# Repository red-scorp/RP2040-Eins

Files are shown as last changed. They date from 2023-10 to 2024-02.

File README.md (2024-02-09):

```
 ______    _______  _______  _______  _   ___  _______         _______  ___   __    _  _______ 
|    _ |  |       ||       ||  _    || | |   ||  _    |       |       ||   | |  |  | ||       |
|   | ||  |    _  ||____   || | |   || |_|   || | |   | ____  |    ___||   | |   |_| ||  _____|
|   |_||_ |   |_| | ____|  || | |   ||       || | |   ||____| |   |___ |   | |       || |_____ 
|    __  ||    ___|| ______|| |_|   ||___    || |_|   |       |    ___||   | |  _    ||_____  |
|   |  | ||   |    | |_____ |       |    |   ||       |       |   |___ |   | | | |   | _____| |
|___|  |_||___|    |_______||_______|    |___||_______|       |_______||___| |_|  |__||_______|
```

# RP2040-Eins Project

The **RP2040-Eins** project aims to create a replacement for the Arduino UNO R3 or Arduino M0 using the RP2040 MCU.

## RP2040-Eins Board

The **RP2040-Eins** board is a 4-layer design intended to accommodate the popular Raspberry Pi RP2040 MCU within the standard Arduino UNO R3 footprint.

This board is crafted in Germany, and its name, "RP2040-Eins", incorporates the German word "Eins" (pronounced as "eye-ns"), which translates to "one". This name choice reflects the use of the same form-factor as the Arduino "Uno", which means "one" in Italian.

Preview:

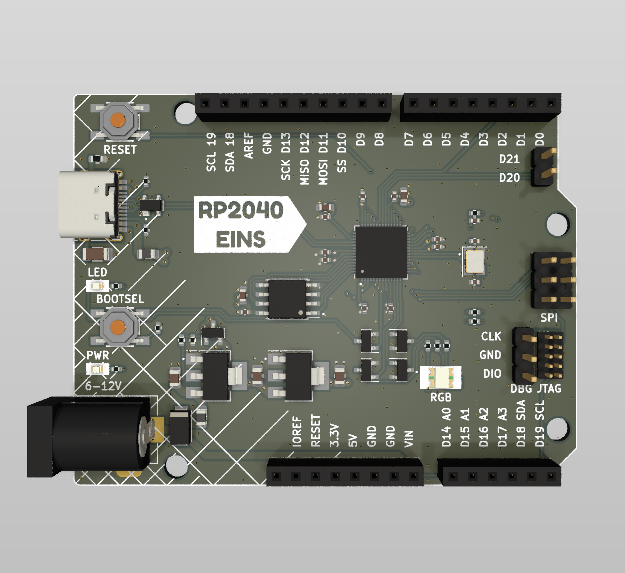
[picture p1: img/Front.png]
RP2040-Eins Front preview

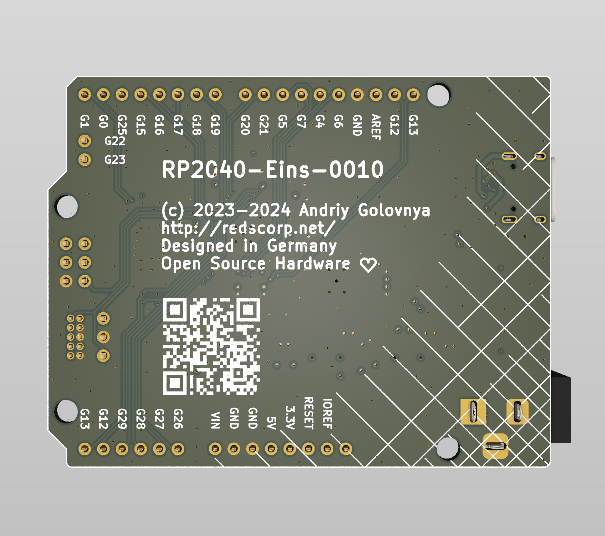
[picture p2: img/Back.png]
RP2040-Eins Back preview

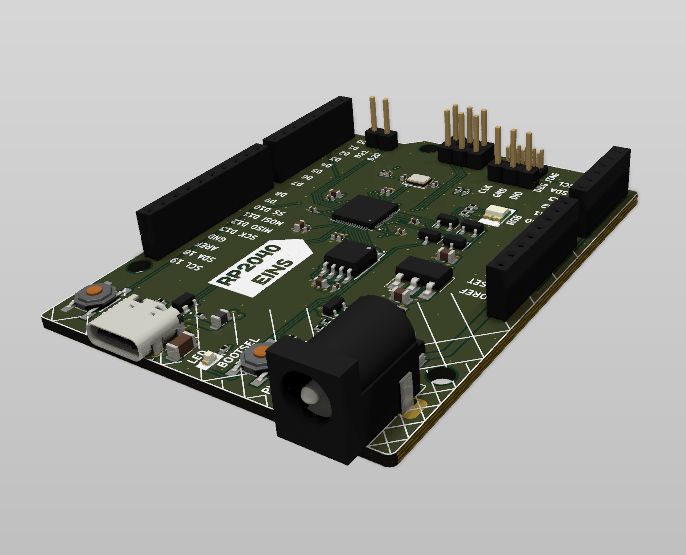
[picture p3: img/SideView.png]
RP2040-Eins Side View preview


You can view the [Schematics in PDF format](doc/RP2040-Eins.pdf) for detailed information.

STEP 3D file is available [with pins](doc/RP2040-Eins.step).

Features:

- Arduino UNO compatible pinout
- Partially compatible with Arduino Nano RP2040 Connect pinout
- Dual-core Cortex-M0+ Raspberry Pi RP2040
- 21 GPIO pins, including 4 analog inputs
- USB Type-C connector
- JTAG and DBG debugging connectors
- LDO-based 5V and 3.3V power supply with a maximum 12V input
- Supports both SOIC and WSON 16MB flash packages
- Includes power, user and RGB LEDs

CAM files, as well as the BOM and CPL files for JLCPCB, are available.

### Board Pinout

Following pinout is used for the board:

| Board Pin | RP2040 Pin | Function | Notes |
| --- | --- | --- | ----- |
| D0 | GPIO1 | UART0 TX | |
| D1 | GPIO0 | UART0 RX | |
| D2 | GPIO25 | | |
| D3 | GPIO15 | | |
| D4 | GPIO16 | | |
| D5 | GPIO17 | | |
| D6 | GPIO18 | | |
| D7 | GPIO19 | | |
| D8 | GPIO20 | | |
| D9 | GPIO21 | | |
| D10 | GPIO5 | SS | |
| D11 | GPIO7 | MOSI | |
| D12 | GPIO4 | MISO | |
| D13 | GPIO6 | SCK | LED |
| D14 A0 | GPIO26 | | |
| D15 A1 | GPIO27 | | |
| D16 A2 | GPIO28 | | |
| D17 A3 | GPIO29 | | |
| D18 | GPIO12 | SDA | |
| D19 | GPIO13 | SCL | |
| D20 | GPIO22 | | |
| D21 | GPIO23 | | |
| LED_R | GPIO9 | | |
| LED_G | GPIO10 | | |
| LED_B | GPIO11 | | |

## Version History

This board exists in a single LDO-based flavor. If you want to use a Buck-based version of this board, please contact me directly.

Each version of the board listed below is tagged in the repository. You can use the tag to checkout the repository to the specific version.

### v1.0b4 - 09.02.2024

v1.0b4 board preview

Last testing release.

- Fixed SPI connector pins layout.
- Renamed Arduino pins as Dxx an added GPIO pin names at the back as Gxx.
- Added 2.54mm 3-pin DBG connector.

### v1.0b3 - 21.11.2023

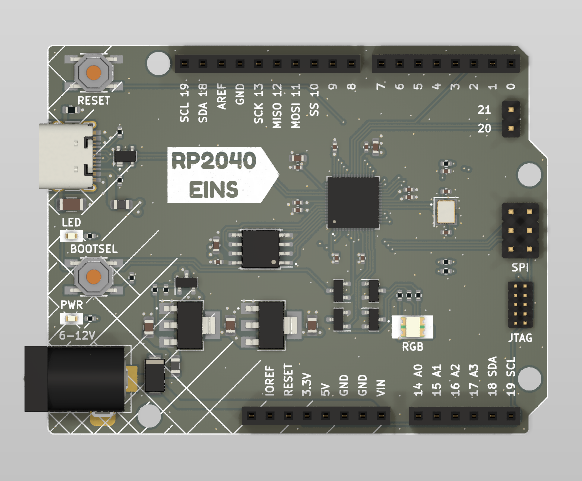
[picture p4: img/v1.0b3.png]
v1.0b3 board preview


Third testing release.

- Moved BOOTSEL button to the edge of the board for easier access when shield is attached.
- Moved QSPI flash closer to the MCU.
- Added Arduino code examples for RGB LED.
- Rearranged routing of several lines.
- Added fancy board name label.
- Added white silkscreen under the LEDs to add light reflection.
- Moved text on the back of the board a bit.
- Removed pull-up resistor from SWCLK line.

### v1.0b2 - 04.11.2023

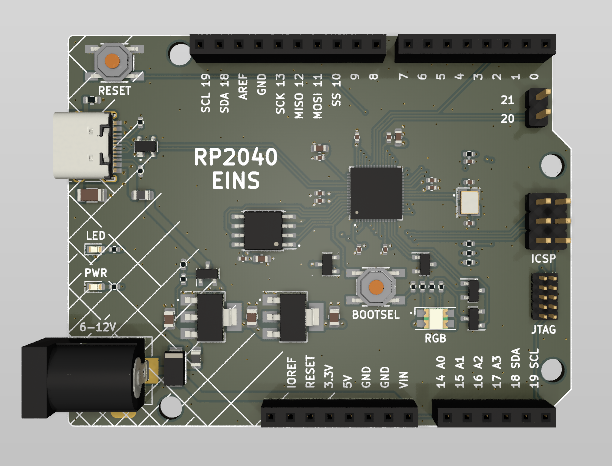
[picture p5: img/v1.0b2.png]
v1.0b2 board preview


Second testing release.

- Added MOSFETs for RGB LED to make it work similarly to user LED.
- Moved few components around.
- Added QR code to the back of the board.

### v1.0b1 - 15.10.2023

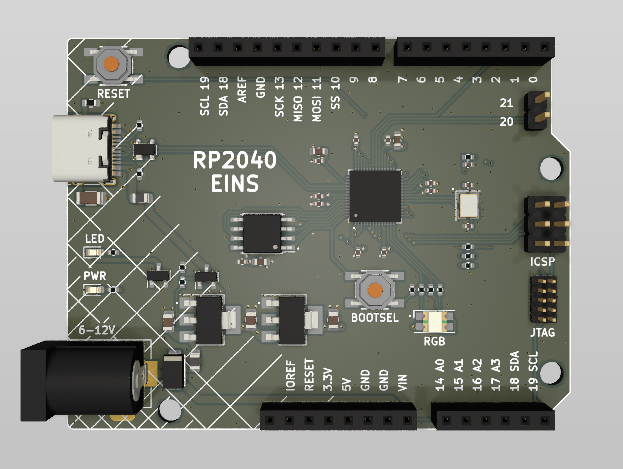
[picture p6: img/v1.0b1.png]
v1.0b1 board preview


Initial release for testing purposes.

## Code Examples

Following code examples are available:

Only Adruino SDK:
- ``src/arduino/rgb_led/rotation_blink.ino`` - blinks RGB LED in rotation individually
- ``src/arduino/rgb_led/rotation_fade.ino`` - fades RGB LED in rotation individually
- ``src/arduino/rgb_led/rotation_fade2.ino`` - fades RGB LED in rotation from one color to another

Arduino SDK with FreeRTOS:
- ``src/arduino/rgb_led/freertos_fade.ino`` - fades RGB LED in rotation individually using FreeRTOS

Please use latest official version of [earlephilhower/arduino-pico](https://github.com/earlephilhower/arduino-pico) and select "RP2040-Eins" board as a target.

## Links

- [Raspberry Pi RP2040 information page](https://www.raspberrypi.com/documentation/microcontrollers/rp2040.html).
- [Arduino UNO R3 information page](https://docs.arduino.cc/retired/boards/arduino-uno-rev3-with-long-pins).
- [Arduino SDK for RP2040 board](https://github.com/earlephilhower/arduino-pico).

## How to Help

Your contributions as code, resources, or finances are welcome! Please contact me directly via email at andriy.golovnya@gmail.com or through my [GitHub profile](https://github.com/red-scorp).

If you'd like to make a financial contribution, you can donate via [PayPal](http://paypal.me/redscorp) or [Ko-Fi](http://ko-fi.com/redscorp). Your support is greatly appreciated.

Thanks in advance!

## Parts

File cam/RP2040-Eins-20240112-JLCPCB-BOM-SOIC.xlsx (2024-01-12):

Qty | Designator | Footprint | JLCPCB Part# | Comment
1 | Q1 | SOT-23 | C15127 | AO3401A
3 | C15,C14,C12 | 0805 | C15850 | 10uF
2 | FB2,FB1 | 0805 | C1015 | GZ2012D101TF
3 | C5,C16,C1 | 0603 | C1604 | 2.2uF
5 | R3,R8,R9,R5,R4 | 0402 | C25744 | 10k
1 | U1 | SOIC-8-208mil | C97521 | W25Q128JVS
1 | SW1,SW2 | SMD | C318884 | TS-1187A-B-A-B
1 | J3 | Plugin,P=2.54mm | C40877 | CONN_A
1 | J1 | Plugin | C16214 | CONN_PWR
7 | R14,R11,R13,R6,R1,R15,R10 | 0402 | C25905 | 5k1
1 | U3 | SOT-223 | C6187 | AMS1117-5.0
1 | D4 | 1210 | C965844 | RGB
1 | Y1 | SMD3225-4P | C9002 | 12MHz
11 | C7,C13,C6,C22,C3,C11,C2,C8,C4,C9,C10 | 0402 | C1525 | 100nF
1 | D5 | SMA(DO-214AC) | C2480 | SS14
1 | U2 | LQFN-56(7x7) | C2040 | RP2040
2 | C20,C19 | 0402 | C1547 | 12pF
2 | D1,D2 | 0603 | C2286 | RED
1 | J4 | Plugin,P=2.54mm | C429957 | CONN_P
4 | Q4,Q3,Q5,Q2 | SOT-23-3L | C20917 | AO3400A
1 | J2 | Plugin,P=2.54mm | C390684 | CONN_ICSP
1 | J9 | Plugin,P=2.54mm | C2935981 | CONN_D2
1 | J7 | SMD,P=1.27mm | C2935953 | JTAG
1 | R7 | 0402 | C11702 | 1k
1 | J10 | SMD | C2689844 | CONN_USB
1 | U5 | SOT-223-3 | C6186 | AMS1117-3.3
1 | C21 | 1206 | C106074 | 4.7nF 1kV
1 | D3 | SOT-143 | C5158049 | PRTR5V0U2X
1 | J8 | Plugin,P=2.54mm | C429957 | CONN_D1
1 | R12 | 0603 | C136593 | 1M
1 | J5 | Plugin,P=2.54mm | C2685154 | CONN_X
1 | J6 | Plugin,P=2.54mm | C2937625 | CONN_DBG

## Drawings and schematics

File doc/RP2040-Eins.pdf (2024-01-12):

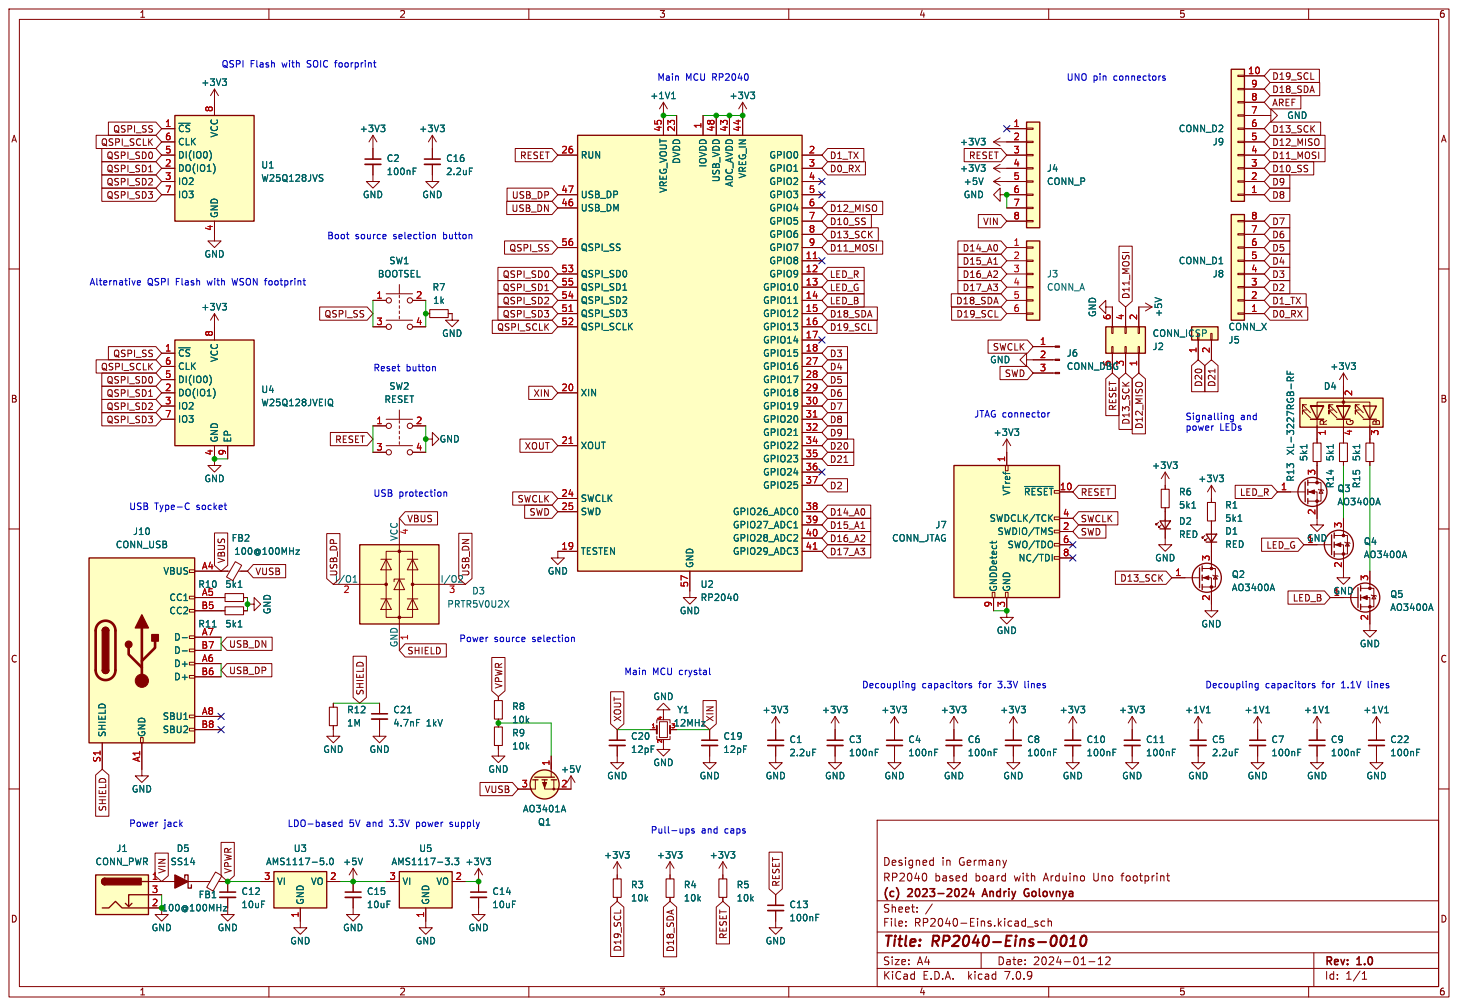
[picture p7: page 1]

1 GPIO8 11 GPIO9 12 GPIO10 13 GPIO11 14 GPIO12 15 GPIO13 16 GPIO14 17 GPIO15 18 TESTEN 19 GPIO0 2 XIN 20 XOUT 21 DVDD 23 SWCLK 24 SWD 25 RUN 26 GPIO16 27 GPIO17 28 GPIO18 29 GPIO1 3 GPIO19 30 GPIO20 31 GPIO21 32 GPIO22 34 GPIO23 35 GPIO24 36 GPIO25 37 GPIO26_ADC0 38 GPIO27_ADC1 39 GPIO2 4 GPIO28_ADC2 40 GPIO29_ADC3 41 ADC_AVDD 43 VREG_IN 44 VREG_VOUT 45 USB_DM 46 USB_DP 47 USB_VDD 48 GPIO3 5 QSPI_SD3 51 QSPI_SCLK 52 QSPI_SD0 53 QSPI_SD2 54 QSPI_SD1 55 QSPI_SS 56 GND 57 GPIO4 6 GPIO5 7 GPIO6 8 GPIO7 9 U2 RP2040 R4

1 GPIO8 11 GPIO9 12 GPIO10 13 GPIO11 14 GPIO12 15 GPIO13 16 GPIO14 17 GPIO15 18 TESTEN 19 GPIO0 2 XIN 20 XOUT 21 DVDD 23 SWCLK 24 SWD 25 RUN 26 GPIO16 27 GPIO17 28 GPIO18 29 GPIO1 3 GPIO19 30 GPIO20 31 GPIO21 32 GPIO22 34 GPIO23 35 GPIO24 36 GPIO25 37 GPIO26_ADC0 38 GPIO27_ADC1 39 GPIO2 4 GPIO28_ADC2 40 GPIO29_ADC3 41 ADC_AVDD 43 VREG_IN 44 VREG_VOUT 45 USB_DM 46 USB_DP 47 USB_VDD 48 GPIO3 5 QSPI_SD3 51 QSPI_SCLK 52 QSPI_SD0 53 QSPI_SD2 54 QSPI_SD1 55 QSPI_SS 56 GND 57 GPIO4 6 GPIO5 7 GPIO6 8 GPIO7 9 R4

XIN QSPI_SD3 XOUT VUSBVPWR SHIELD

3 SWDCLK/TCK 4 SWO/TDO 6 NC/TDI 8 GNDDetect 9 GND
J7 CONN_JTAG

3 SWDCLK/TCK 4 SWO/TDO 6 NC/TDI 8 GNDDetect 9

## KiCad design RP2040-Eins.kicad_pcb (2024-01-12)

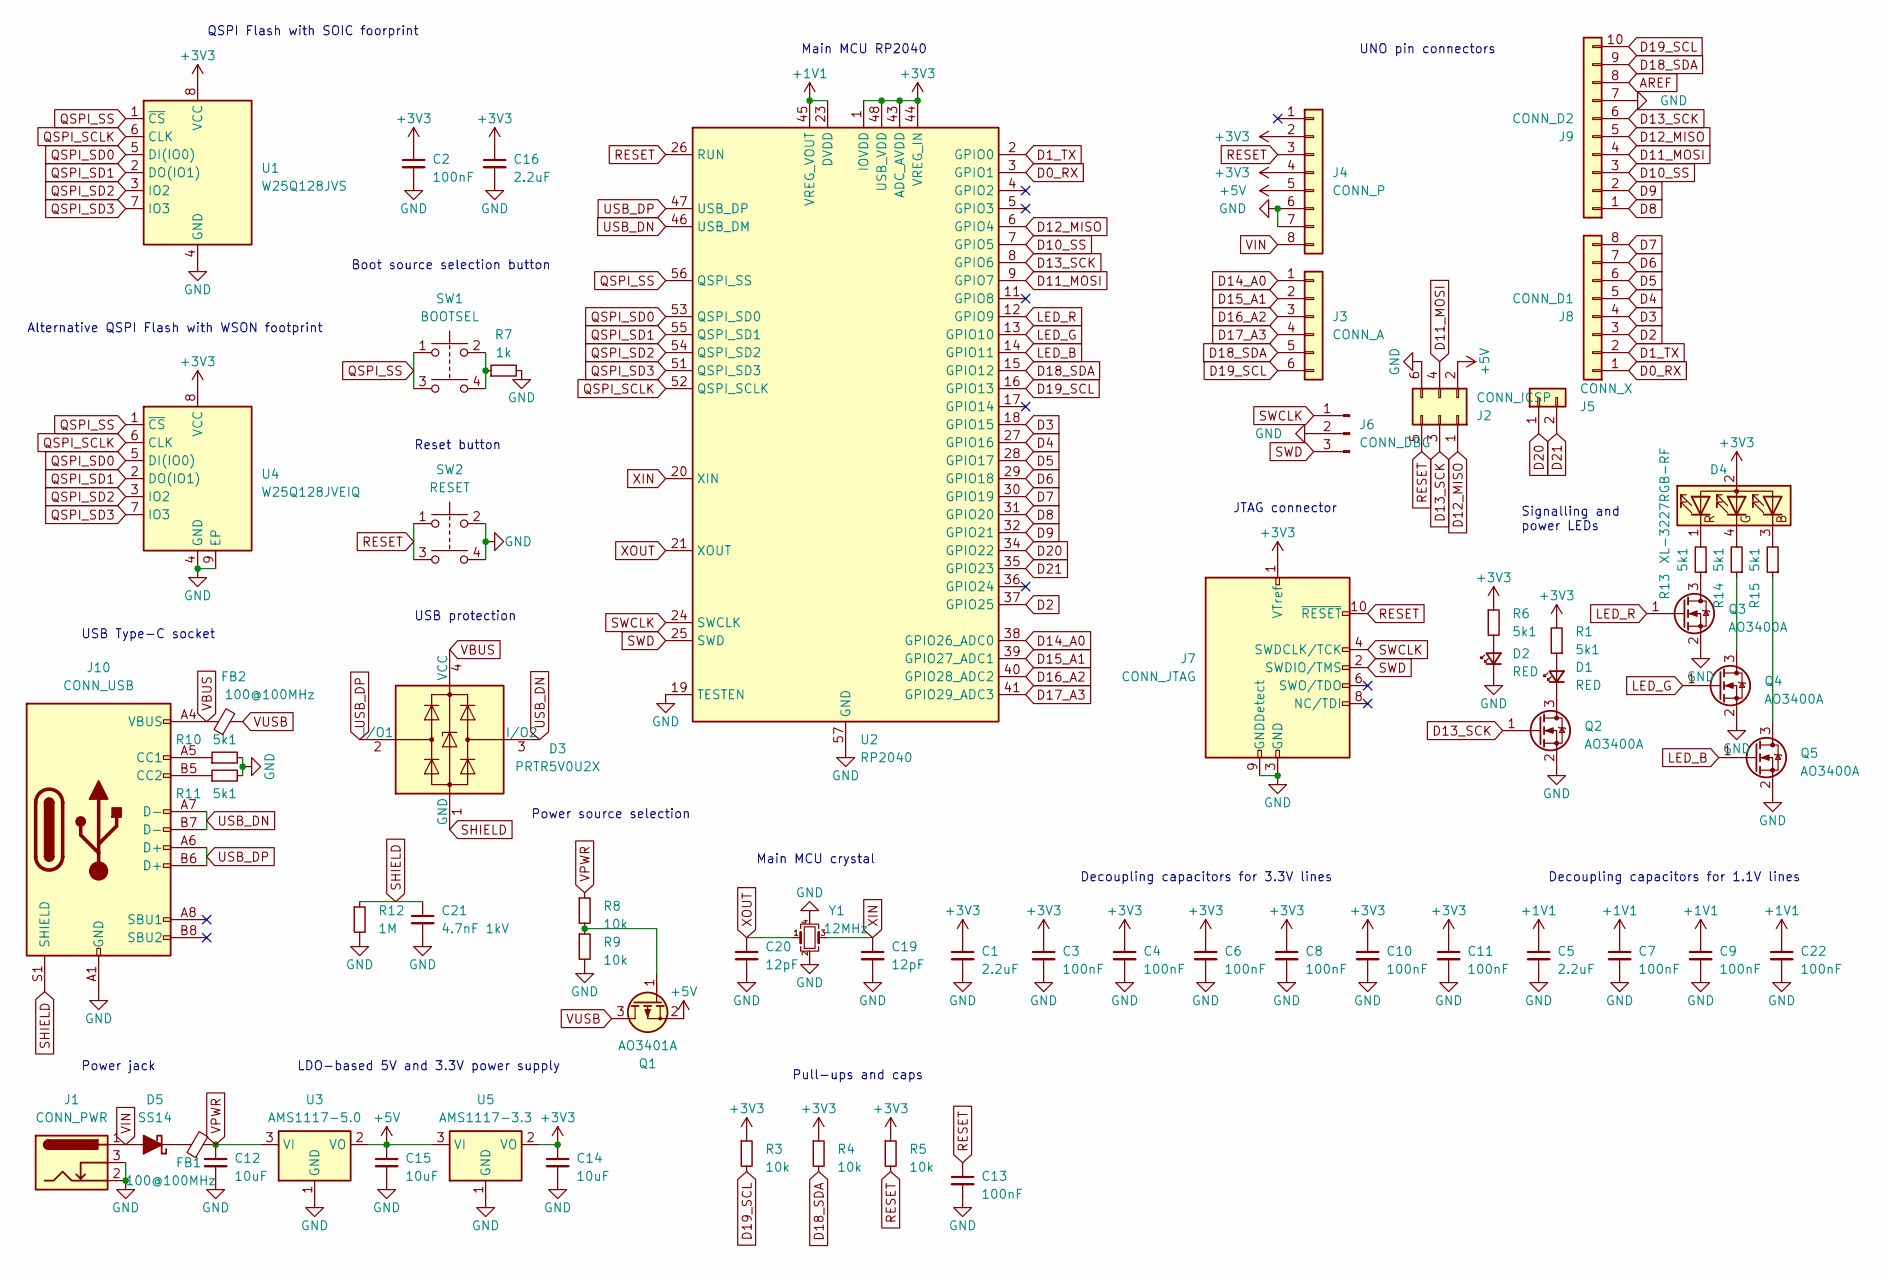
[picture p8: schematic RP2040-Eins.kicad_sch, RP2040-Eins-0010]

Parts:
C1, C5, C16: 2.2uF; C_0603_1608Metric
C2, C3, C4, C6, C7, C8, C9, C10, C11, C13, C22: 100nF; C_0402_1005Metric
C12, C14, C15: 10uF; C_0805_2012Metric
C19, C20: 12pF; C_0402_1005Metric
C21: 4.7nF 1kV; C_1206_3216Metric
D1, D2: RED; LED_0603_1608Metric
D3: PRTR5V0U2X; SOT-143
D4: XL-3227RGB-RF; LED_RGB_1210
D5: SS14; D_DO-214AC_SMA
FB1, FB2: 100@100MHz; L_0805_2012Metric
J1: CONN_PWR; BarrelJack_Horizontal
J2: CONN_ICSP; PinHeader_2x03_P2.54mm_Vertical
J3: CONN_A; PinSocket_1x06_P2.54mm_Vertical
J4: CONN_P; PinSocket_1x08_P2.54mm_Vertical
J5: CONN_X; PinHeader_1x02_P2.54mm_Vertical
J6: CONN_DBG; PinHeader_1x03_P2.54mm_Vertical
J7: CONN_JTAG; PinHeader_2x05_P1.27mm_Vertical
J8: CONN_D1; PinSocket_1x08_P2.54mm_Vertical
J9: CONN_D2; PinSocket_1x10_P2.54mm_Vertical
J10: CONN_USB; USB_C_Receptacle_HRO_TYPE-C-31-M-12
Q1: AO3401A; SOT-23
Q2, Q3, Q4, Q5: AO3400A; SOT-23
R1, R6, R10, R11, R13, R14, R15: 5k1; R_0402_1005Metric
R3, R4, R5, R8, R9: 10k; R_0402_1005Metric
R7: 1k; R_0402_1005Metric
R12: 1M; R_0603_1608Metric
SW1: BOOTSEL; Button_Tact_Sqkg
SW2: RESET; Button_Tact_Sqkg
U1: W25Q128JVS; SOIC-8_5.23x5.23mm_P1.27mm
U2: RP2040; QFN-56-1EP_7x7mm_P0.4mm_EP3.2x3.2mm
U3: AMS1117-5.0; SOT-223-3_TabPin2
U4: W25Q128JVEIQ; WSON-8-1EP_6x5mm_P1.27mm_EP3.4x4.3mm
U5: AMS1117-3.3; SOT-223-3_TabPin2
Y1: 12MHz; Crystal_SMD_3225-4Pin_3.2x2.5mm

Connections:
+1V1: C5.1, C7.1, C9.1, C22.1, U2.23 (DVDD), U2.45 (VREG_VOUT), U2.50 (DVDD)
+3V3: C1.1, C2.1, C3.1, C4.1, C6.1, C8.1, C10.1, C11.1, C14.1, C16.1, D4.2 (A), J4.2, J4.4, J7.1 (VTref), R1.2, R3.1, R4.1, R5.1, R6.1, U1.8 (VCC), U2.1 (IOVDD), U2.10 (IOVDD), U2.22 (IOVDD), U2.33 (IOVDD), U2.42 (IOVDD), U2.43 (ADC_AVDD), U2.44 (VREG_IN), U2.48 (USB_VDD), U2.49 (IOVDD), U4.8 (VCC), U5.2 (VO)
+5V: C15.1, J2.2, J4.5, Q1.2 (S), U3.2 (VO), U5.3 (VI)
AREF: J9.8
D0_RX: J8.1, U2.3 (GPIO1)
D1_TX: J8.2, U2.2 (GPIO0)
D2: J8.3, U2.37 (GPIO25)
D3: J8.4, U2.18 (GPIO15)
D4: J8.5, U2.27 (GPIO16)
D5: J8.6, U2.28 (GPIO17)
D6: J8.7, U2.29 (GPIO18)
D7: J8.8, U2.30 (GPIO19)
D8: J9.1, U2.31 (GPIO20)
D9: J9.2, U2.32 (GPIO21)
D10_SS: J9.3, U2.7 (GPIO5)
D11_MOSI: J2.4, J9.4, U2.9 (GPIO7)
D12_MISO: J2.1, J9.5, U2.6 (GPIO4)
D13_SCK: J2.3, J9.6, Q2.1 (G), U2.8 (GPIO6)
D14_A0: J3.1, U2.38 (GPIO26_ADC0)
D15_A1: J3.2, U2.39 (GPIO27_ADC1)
D16_A2: J3.3, U2.40 (GPIO28_ADC2)
D17_A3: J3.4, U2.41 (GPIO29_ADC3)
D18_SDA: J3.5, J9.9, R4.2, U2.15 (GPIO12)
D19_SCL: J3.6, J9.10, R3.2, U2.16 (GPIO13)
D20: J5.1, U2.34 (GPIO22)
D21: J5.2, U2.35 (GPIO23)
GND: C1.2, C2.2, C3.2, C4.2, C5.2, C6.2, C7.2, C8.2, C9.2, C10.2, C11.2, C12.2, C13.2, C14.2, C15.2, C16.2, C19.2, C20.2, C21.2, C22.2, D2.1 (K), J1.2, J1.3, J2.6, J4.6, J4.7, J6.2, J7.3 (GND), J7.5 (GND), J7.9 (GNDDetect), J9.7, J10.A1 (GND), J10.A12 (GND), J10.B1 (GND), J10.B12 (GND), Q2.2 (S), Q3.2 (S), Q4.2 (S), Q5.2 (S), R7.2, R9.2, R10.2, R11.2, R12.2, SW2.2, SW2.4, U1.4 (GND), U2.19 (TESTEN), U2.57 (GND), U3.1 (GND), U4.4 (GND), U4.9 (EP), U5.1 (GND), Y1.2, Y1.4
LED_B: Q5.1 (G), U2.14 (GPIO11)
LED_G: Q4.1 (G), U2.13 (GPIO10)
LED_R: Q3.1 (G), U2.12 (GPIO9)
unnamed: D1.2 (A), R1.1
unnamed: D1.1 (K), Q2.3 (D)
unnamed: D2.2 (A), R6.2
unnamed: D4.3 (BK), R15.2
unnamed: D4.4 (GK), R14.2
unnamed: D4.1 (RK), R13.2
unnamed: D5.1 (K), FB1.1
unnamed: J10.A5 (CC1), R10.1
unnamed: J10.B5 (CC2), R11.1
unnamed: Q1.1 (G), R8.2, R9.1
unnamed: Q3.3 (D), R13.1
unnamed: Q4.3 (D), R14.1
unnamed: Q5.3 (D), R15.1
unnamed: R7.1, SW1.2, SW1.4
QSPI_SCLK: U1.6 (CLK), U2.52 (QSPI_SCLK), U4.6 (CLK)
QSPI_SD0: U1.5 (DI(IO0)), U2.53 (QSPI_SD0), U4.5 (DI(IO0))
QSPI_SD1: U1.2 (DO(IO1)), U2.55 (QSPI_SD1), U4.2 (DO(IO1))
QSPI_SD2: U1.3 (IO2), U2.54 (QSPI_SD2), U4.3 (IO2)
QSPI_SD3: U1.7 (IO3), U2.51 (QSPI_SD3), U4.7 (IO3)
QSPI_SS: SW1.1, SW1.3, U1.1 (~CS), U2.56 (QSPI_SS), U4.1 (~CS)
RESET: C13.1, J2.5, J4.3, J7.10 (~RESET), R5.2, SW2.1, SW2.3, U2.26 (RUN)
SHIELD: C21.1, D3.1 (GND), J10.S1 (SHIELD), R12.1
SWCLK: J6.1, J7.4 (SWDCLK/TCK), U2.24 (SWCLK)
SWD: J6.3, J7.2 (SWDIO/TMS), U2.25 (SWD)
USB_DN: D3.3 (I/O2), J10.A7 (D-), J10.B7 (D-), U2.46 (USB_DM)
USB_DP: D3.2 (I/O1), J10.A6 (D+), J10.B6 (D+), U2.47 (USB_DP)
VBUS: D3.4 (VCC), FB2.1, J10.A4 (VBUS), J10.A9 (VBUS), J10.B4 (VBUS), J10.B9 (VBUS)
VIN: D5.2 (A), J1.1, J4.8
VPWR: C12.1, FB1.2, R8.1, U3.3 (VI)
VUSB: FB2.2, Q1.3 (D)
XIN: C19.1, U2.20 (XIN), Y1.3
XOUT: C20.1, U2.21 (XOUT), Y1.1

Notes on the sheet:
USB protection
Alternative QSPI Flash with WSON footprint
UNO pin connectors
Main MCU RP2040
Power source selection
Power jack
Decoupling capacitors for 3.3V lines
Main MCU crystal
Decoupling capacitors for 1.1V lines
Pull-ups and caps
Signalling and power LEDs
JTAG connector
Reset button
USB Type-C socket
Boot source selection button
LDO-based 5V and 3.3V power supply
QSPI Flash with SOIC foorprint

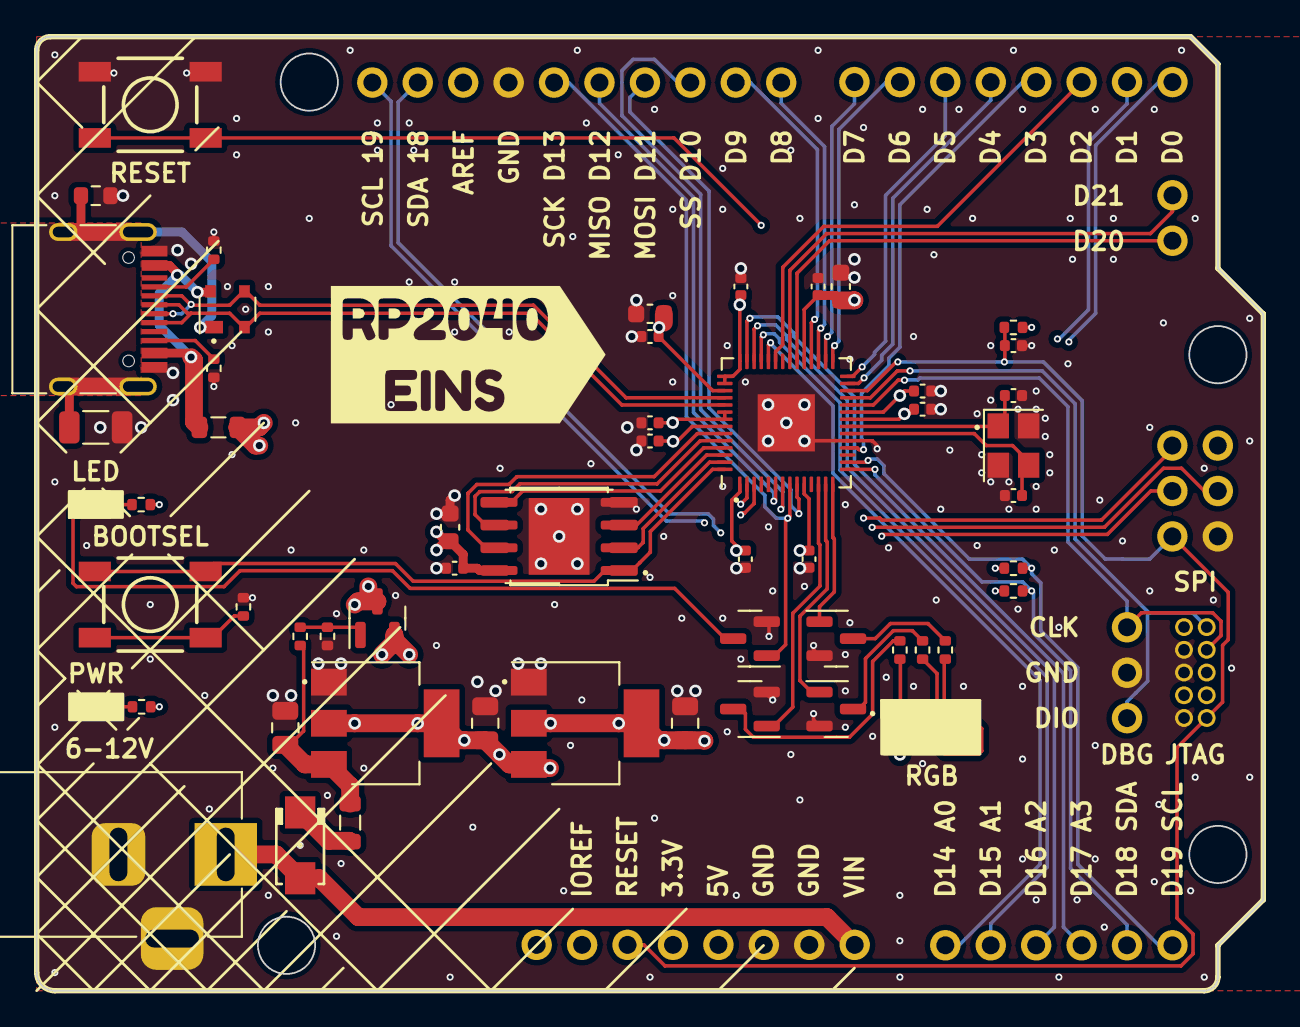
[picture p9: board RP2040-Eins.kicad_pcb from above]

Board: 4 copper layers, 68.6 x 53.3 mm, 66 parts (1 on the bottom side), 61 nets.

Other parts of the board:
G1: QR-CODE; LOGO
G2: BOARD-LABEL; kibuzzard-654A67CC

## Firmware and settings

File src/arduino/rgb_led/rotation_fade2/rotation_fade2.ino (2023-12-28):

/**
 * @file rotation_fade2.ino
 * @brief Fade the RGB LED in rotation
 *
 * This program fades the RGB LED in rotation.
 * The LED is fades from red to green, then from green to blue, and then from blue to red.
 * This process is repeated.
 *
 * @date 2023/12/28
 * @version 1.0.0
 */

#include <Arduino.h>

/* RGB LED pin numbers are defined in the rp2040 SDK as PIN_LED_R, PIN_LED_G and PIN_LED_B when you select RP2040-Eins as a target board */

const int fadeDuration = 1000; // 1 second fade duration

void setup() {
  // Set the pin modes for the LEDs as outputs
  pinMode(PIN_LED_R, OUTPUT);
  pinMode(PIN_LED_G, OUTPUT);
  pinMode(PIN_LED_B, OUTPUT);
}

void loop() {
  // Rotate the fade colors
  fadeLED(PIN_LED_R, PIN_LED_G);
  fadeLED(PIN_LED_G, PIN_LED_B);
  fadeLED(PIN_LED_B, PIN_LED_R);
}

void fadeLED(int fromPin, int toPin) {
  // Fade on LED on and fade another LED off
  for (int brightness = 0; brightness <= 255; brightness++) {
    analogWrite(fromPin, 255 - brightness);
    analogWrite(toPin, brightness);
    delay(fadeDuration / 255);
  }
}

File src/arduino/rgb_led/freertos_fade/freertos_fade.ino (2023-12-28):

/**
 * @file freertos_fade.ino
 * @brief Fade the RGB LED in rotation using FreeRTOS
 *
 * This program fades the RGB LED in rotation using FreeRTOS.
 * The red LED is fades on and then faded out, the green LED is fades on and then faded out, and the blue LED is fades on and then faded out.
 * All of these are done in parallel using several FreeRTOS tasks.
 * This process is repeated.
 *
 * @date 2023/12/28
 * @version 1.0.0
 */

#include <Arduino.h>

#include <FreeRTOS.h>
#include <task.h>

/* RGB LED pin numbers are defined in the rp2040 SDK as PIN_LED_R, PIN_LED_G and PIN_LED_B when you select RP2040-Eins as a target board */

// Define fade durations (in milliseconds) for each LED
const int fadeDurationRed = 1000;
const int fadeDurationGreen = 3000;
const int fadeDurationBlue = 5000;

void setup() {
  // Initialize LED pins as outputs
  pinMode(PIN_LED_R, OUTPUT);
  pinMode(PIN_LED_G, OUTPUT);
  pinMode(PIN_LED_B, OUTPUT);

  // Create FreeRTOS tasks for fading each LED
  xTaskCreate(fadeRedLED, "Fade Red LED", 128, NULL, 1, NULL);
  xTaskCreate(fadeGreenLED, "Fade Green LED", 128, NULL, 1, NULL);
  xTaskCreate(fadeBlueLED, "Fade Blue LED", 128, NULL, 1, NULL);

  // Start the FreeRTOS scheduler is not needed in RP2040 flavour of FreeRTOS library implementation
  // vTaskStartScheduler();
}

void loop() {
  // Nothing to do in loop() as the FreeRTOS tasks will handle the LED fading
  vTaskDelay(pdMS_TO_TICKS(1000)); // wait for a second
}

void fadeRedLED(void *pvParameters) {
  while (true) {
    // Fade red LED up
    for (int brightness = 0; brightness <= 255; brightness++) {
      analogWrite(PIN_LED_R, brightness);
      vTaskDelay(pdMS_TO_TICKS(fadeDurationRed) / 255);
    }

    // Fade red LED down
    for (int brightness = 255; brightness >= 0; brightness--) {
      analogWrite(PIN_LED_R, brightness);
      vTaskDelay(pdMS_TO_TICKS(fadeDurationRed) / 255);
    }
  }
}

void fadeGreenLED(void *pvParameters) {
  while (true) {
    // Fade green LED up
    for (int brightness = 0; brightness <= 255; brightness++) {
      analogWrite(PIN_LED_G, brightness);
      vTaskDelay(pdMS_TO_TICKS(fadeDurationGreen) / 255);
    }

    // Fade green LED down
    for (int brightness = 255; brightness >= 0; brightness--) {
      analogWrite(PIN_LED_G, brightness);
      vTaskDelay(pdMS_TO_TICKS(fadeDurationGreen) / 255);
    }
  }
}

void fadeBlueLED(void *pvParameters) {
  while (true) {
    // Fade blue LED up
    for (int brightness = 0; brightness <= 255; brightness++) {
      analogWrite(PIN_LED_B, brightness);
      vTaskDelay(pdMS_TO_TICKS(fadeDurationBlue) / 255);
    }

    // Fade blue LED down
    for (int brightness = 255; brightness >= 0; brightness--) {
      analogWrite(PIN_LED_B, brightness);
      vTaskDelay(pdMS_TO_TICKS(fadeDurationBlue) / 255);
    }
  }
}

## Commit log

2023-09-20 Added LDO power and UNO pinout
    [RP2040-Eins.kicad_sch]
2023-09-21 Added few components
    [RP2040-Eins.kicad_sch]
2023-09-22 Added more components to schematics
    [RP2040-Eins.kicad_sch]
2023-09-22 Added ICSP connector. Changed JTAG connector footprint.
    [RP2040-Eins.kicad_pcb, RP2040-Eins.kicad_sch]
2023-09-23 Added board edge
    [RP2040-Eins.kicad_pcb]
2023-09-24 Exchanged Arduino board shape with separate connectors
    [RP2040-Eins.kicad_pcb, RP2040-Eins.kicad_sch]
2023-09-24 Added quartz caps. Moved stuff around.
    [RP2040-Eins.kicad_pcb, RP2040-Eins.kicad_sch]
2023-09-25 Switched to USB-C with all stuff around it.
    [RP2040-Eins.kicad_pcb, RP2040-Eins.kicad_sch]
2023-09-26 Moved stuff around
    [RP2040-Eins.kicad_pcb, RP2040-Eins.kicad_sch]
2023-09-26 Added polarity reversion protection diode
    [RP2040-Eins.kicad_pcb, RP2040-Eins.kicad_sch]
2023-09-29 Added few traces
    [RP2040-Eins.kicad_pcb]
2023-09-30 Put schottky diode instead of normal one.
    [RP2040-Eins.kicad_pcb, RP2040-Eins.kicad_sch]
2023-09-30 Simplified the schematics a bit
    [RP2040-Eins.kicad_pcb, RP2040-Eins.kicad_sch]
2023-09-30 Added ferrite beads. Changed power routing.
    [RP2040-Eins.kicad_pcb, RP2040-Eins.kicad_sch]
2023-10-03 Added RGB LED
    [RP2040-Eins.kicad_pcb, RP2040-Eins.kicad_sch]
2023-10-03 Fixed RGB LED orientation
    [RP2040-Eins.kicad_pcb, RP2040-Eins.kicad_sch]
2023-10-05 Added front silkscreen labels
    [RP2040-Eins.kicad_pcb]
2023-10-05 Added back side silk labels
    [RP2040-Eins.kicad_pcb]
2023-10-05 Added board description on the back silk.
    [RP2040-Eins.kicad_pcb, RP2040-Eins.kicad_sch]
2023-10-06 Rewired some traces away from power layer. Removed pin labels from bottom side.
    [RP2040-Eins.kicad_pcb]
2023-10-06 Added few board decorations
    [RP2040-Eins.kicad_pcb]
2023-10-06 Added README.md prototype
2023-10-08 Added aggregate BoM file (includes both WSON and SOIC flash parts)
    [RP2040-Eins-20231007-BOM-JLCPCB.xlsx]
2023-10-08 Renamed BOM file
    [RP2040-Eins-20231007-JLCPCB-BOM.xlsx]
2023-10-08 Added aggregate CPL file (includes both WSON and SOIC flash parts)
    [RP2040-Eins-20231007-JLCPCB-CPL.xlsx]
2023-10-08 Added missing THT components
    [RP2040-Eins-20231007-JLCPCB-CPL.xlsx]
2023-10-08 Split BoM and CPL into WSON and SOIC versions for easier ordering
    [RP2040-Eins-20231007-JLCPCB-BOM-SOIC.xlsx, RP2040-Eins-20231007-JLCPCB-BOM-WSON.xlsx, RP2040-Eins-20231007-JLCPCB-BOM.xlsx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]
2023-10-08 Rotated several components to fit manufacturer's placement
    [RP2040-Eins-20231007-JLCPCB-CPL-SOIC.xlsx, RP2040-Eins-20231007-JLCPCB-CPL-WSON.xlsx]
2023-10-08 Added center line marker for pins headers
    [RP2040-Eins.kicad_pcb]
2023-10-14 Adjusted connector positions.
    [RP2040-Eins-20231007-JLCPCB-CPL-SOIC.xlsx, RP2040-Eins-20231007-JLCPCB-CPL-WSON.xlsx]
2023-10-15 Moves few stuff around
    [RP2040-Eins.kicad_pcb, RP2040-Eins.kicad_sch]
2023-10-15 Generated PDF schematics
2023-10-15 Generated CAM files
    [RP2040-Eins-20231015-JLCPCB-BOM-SOIC.xlsx, RP2040-Eins-20231015-JLCPCB-BOM-WSON.xlsx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]
2023-10-16 Fixed 1M resistor code
    [RP2040-Eins-20231015-JLCPCB-BOM-SOIC.xlsx, RP2040-Eins-20231015-JLCPCB-BOM-WSON.xlsx]
2023-10-21 Added mosfets for RGB LED. Moved staff around.
    [RP2040-Eins.kicad_pcb, RP2040-Eins.kicad_sch]
2023-11-02 Moved stuff around.
    [RP2040-Eins.kicad_pcb, RP2040-Eins.kicad_sch]
2023-11-03 Added QR Code on the back side.
    [RP2040-Eins.kicad_pcb, RP2040-Eins.kicad_sch]
2023-11-04 Generated BOM and CPL files
    [RP2040-Eins-20231015-JLCPCB-BOM-SOIC.xlsx, RP2040-Eins-20231015-JLCPCB-BOM-WSON.xlsx, RP2040-Eins-20231104-JLCPCB-BOM-SOIC.xlsx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]
2023-11-07 Moved BOOTSEL button closer to the front edge of the board. Moved stuff around to fit better.
    [RP2040-Eins.kicad_pcb]
2023-11-07 Added fancy label. Moved some texts around.
    [RP2040-Eins.kicad_pcb]
2023-11-07 Moved QSPI flash chip closer to the MCU
    [RP2040-Eins.kicad_pcb]
2023-11-07 Added white color under the LEDs to add light reflection.
    [RP2040-Eins.kicad_pcb]
2023-11-08 Simplified routing a bit.
    [RP2040-Eins.kicad_pcb]
2023-11-09 Added rotation_blink.ino arduino example.
2023-11-09 Added rotation_fade.ino arduino example.
2023-11-09 Added rotation_fade2.ino arduino example.
2023-11-09 Fixed end of title comment.
    [rotation_blink.ino, rotation_fade.ino]
2023-11-09 Added arduino examples into README.md
2023-11-09 Fixed example code. Added comments.
    [rotation_blink.ino, rotation_fade.ino, rotation_fade2.ino]
2023-11-12 Changed 6p connector id
    [RP2040-Eins-20231104-JLCPCB-BOM-SOIC.xlsx, RP2040-Eins-20231104-JLCPCB-BOM-WSON.xlsx]
2023-11-12 Updated release date information
    [RP2040-Eins.kicad_pcb, RP2040-Eins.kicad_sch]
2023-11-12 Generated PDF schematic
2023-11-12 Updated board v1.0b3 description
2023-11-18 Selected another equivalent parts to cover shortage
    [RP2040-Eins-20231112-JLCPCB-BOM-SOIC.xlsx, RP2040-Eins-20231112-JLCPCB-BOM-WSON.xlsx]
2023-11-21 Removed pull-up resistor for SWDCLK line.
    [RP2040-Eins.kicad_pcb, RP2040-Eins.kicad_sch]
2023-11-30 Used proper FreeRTOS delay timer definition
2023-12-03 Fixed typo
    [RP2040-Eins.kicad_sch]
2023-12-23 Fixed SPI connector pins layout
    [RP2040-Eins.kicad_pcb, RP2040-Eins.kicad_sch]
2023-12-29 Added board pinout information
2023-12-30 Renamed Arduino pins as Dxx. Added GPIO pin names at the back as Gxx.
    [RP2040-Eins.kicad_pcb]
2024-01-12 Added 2.54mm 3-pin DBG connector
    [RP2040-Eins.kicad_pcb, RP2040-Eins.kicad_sch]

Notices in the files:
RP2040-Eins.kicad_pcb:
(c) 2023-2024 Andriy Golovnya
